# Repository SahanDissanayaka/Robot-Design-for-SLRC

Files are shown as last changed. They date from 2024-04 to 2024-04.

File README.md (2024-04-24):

# Robot Design for SLRC

## About SLRC
The Sri Lankan Robotics Challenge (SLRC) is a competition organized by the Department of Electronic and Telecommunication Engineering, University of Moratuwa. It has two categories: the School Category and the University Category.

## The Team
We are a team of five undergraduates from the Department of Electronic and Telecommunication Engineering, University of Moratuwa, known collectively as "We are Groot." Our team members are:

1. Sahan Dissanayaka
2. Senum Dodangoda
3. Sandaru Liyanaarachchi
4. Pasindu Kulasingham
5. Dilshan Nuwantha

Team

We proudly achieved a top 15 position in the university category and emerged as finalists in the competition.

## Our Task
Our project tasks are inspired by the concept of infinity stones in the Avengers Movie. For detailed information, please refer to the attached PDF document.

[Download Task PDF](https://ent.uom.lk/wp-content/uploads/2024/01/SLRC-2024-University-Category-v1.pdf)

## Our Robot
R2
R1

## Project Tasks
Consists of three planets
1. Planet A - Mountains in Vormir
2. Planet B - Ruins in Sakaar
3. Planet C - Thanos’s Home

- Line Following
- Wall Color Detection
- Color Junction Detection
- 3D Object Detection
- Metal Box Detection and Grabbing
- Wall Following
- Obstacle Height Detection

## Methodology

Each task was executed using advanced sensors and control algorithms:

### Line Following
Utilized an IR array in conjunction with a PID controller for accurate line tracking.

### Wall Color Detection
Employed a ToF sensor for wall detection and a rear-mounted color sensor for precise color identification.

### Color Junction Detection
Utilized strategically placed under-mounted color sensors to detect color junctions effectively.

### 3D Object Detection
Utilized advanced ToF sensor technology to accurately detect the shapes of objects.

### Metal Box Detection and Grabbing
Implemented conductivity testing to identify metal boxes and utilized a robotic arm for efficient grabbing.

### Wall Following
Employed a combination of front and side-mounted ultrasonic sensors for effective wall following.

### Height Detection
Utilized a combination of ToF and ultrasonic sensors to accurately measure object heights.

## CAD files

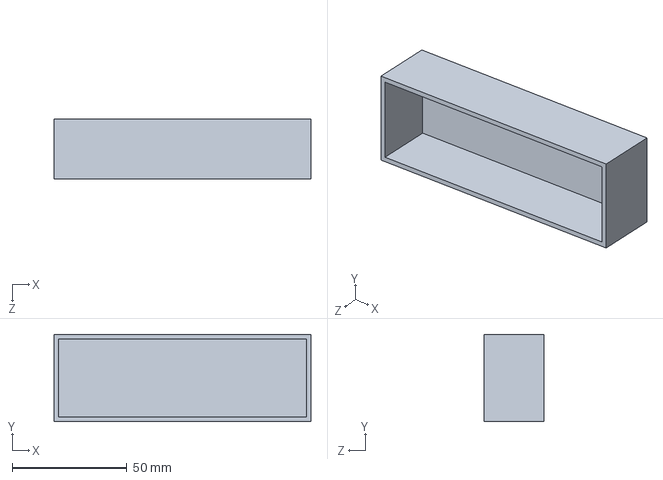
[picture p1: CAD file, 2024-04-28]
SolidWorks/Battery Holder/Assem1.SLDASM
112.0 x 38.0 x 26.0 mm

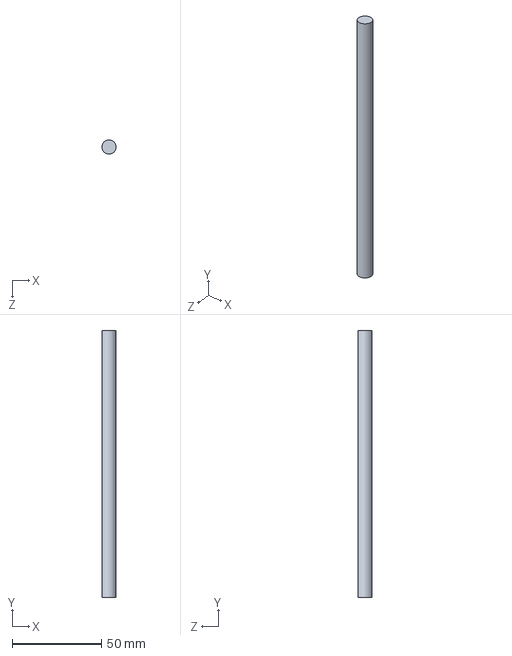
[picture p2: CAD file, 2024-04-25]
Robo Arm/rod right.SLDPRT
7.96 x 150.0 x 8.00 mm

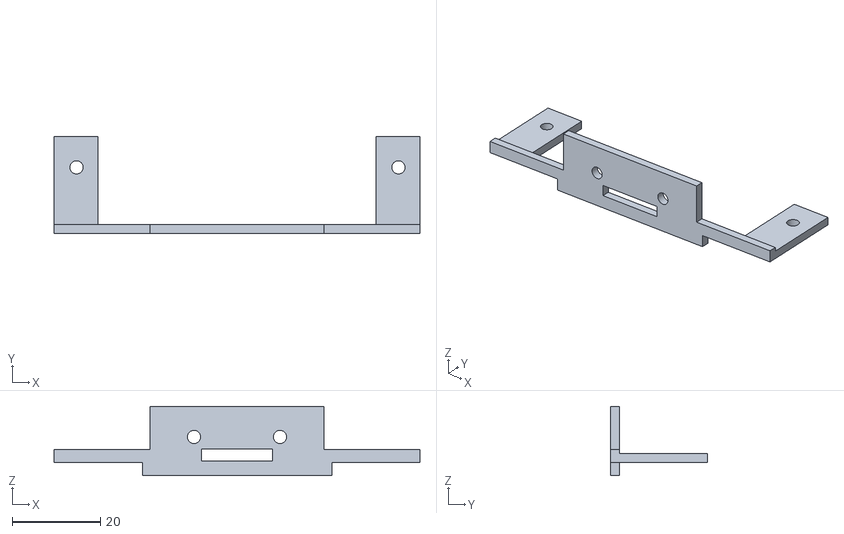
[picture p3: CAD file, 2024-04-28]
SolidWorks/Enclosure/3D Print/ToF sensor Front Holder.STL
83.0 x 22.0 x 15.8

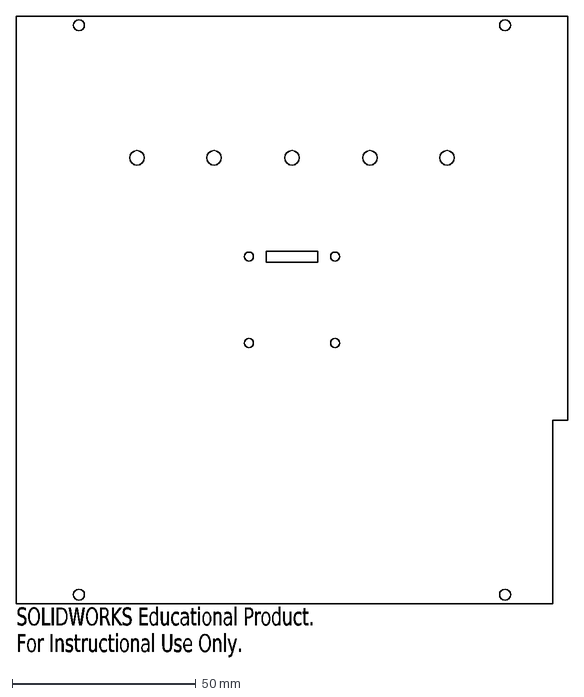
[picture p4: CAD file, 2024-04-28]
SolidWorks/Enclosure/Laser Cut/Top Part.DXF
SOLIDWORKS Educational Product.
For Instructional Use Only.

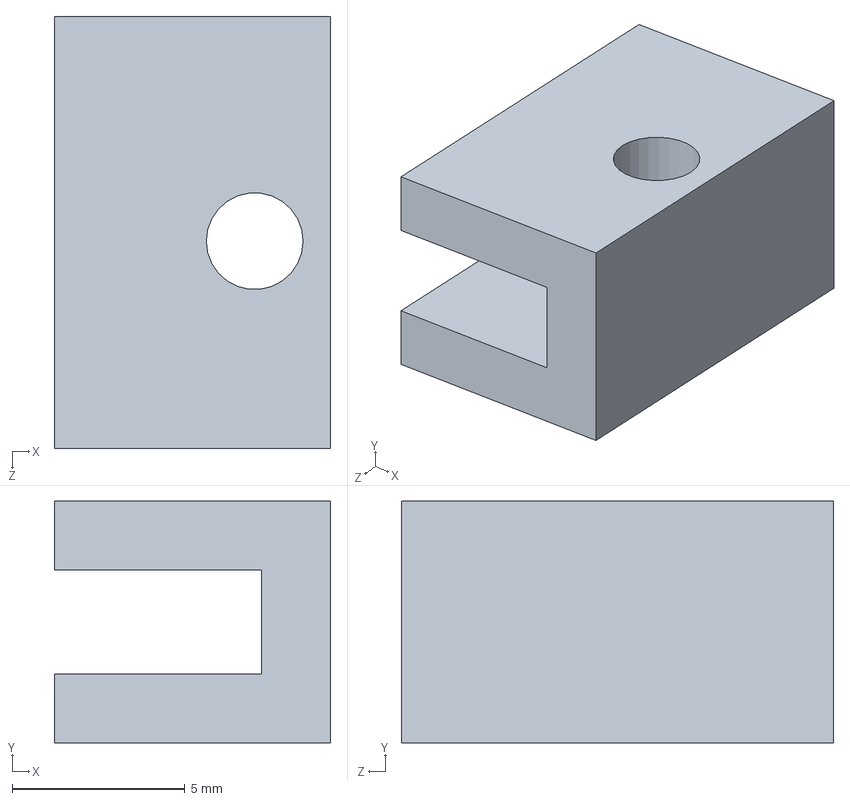
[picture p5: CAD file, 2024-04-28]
SolidWorks/Enclosure/Servo Holder.SLDPRT
8.00 x 7.00 x 12.5 mm

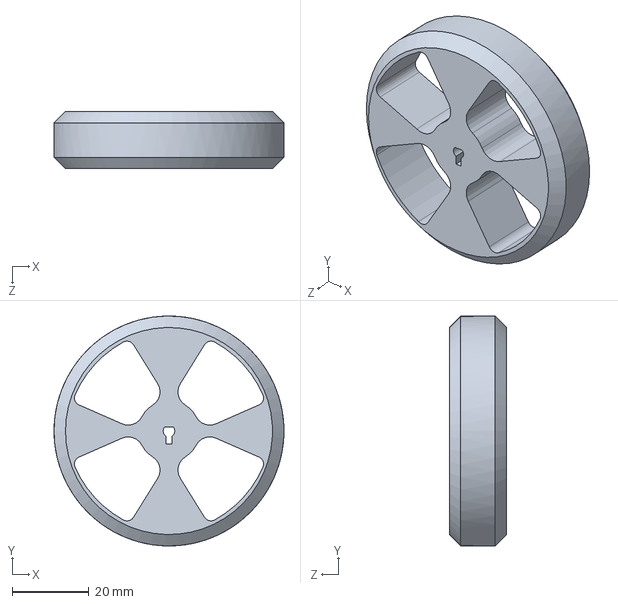
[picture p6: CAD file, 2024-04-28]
SolidWorks/Wheel/6cm.SLDPRT
60.0 x 60.0 x 15.0 mm

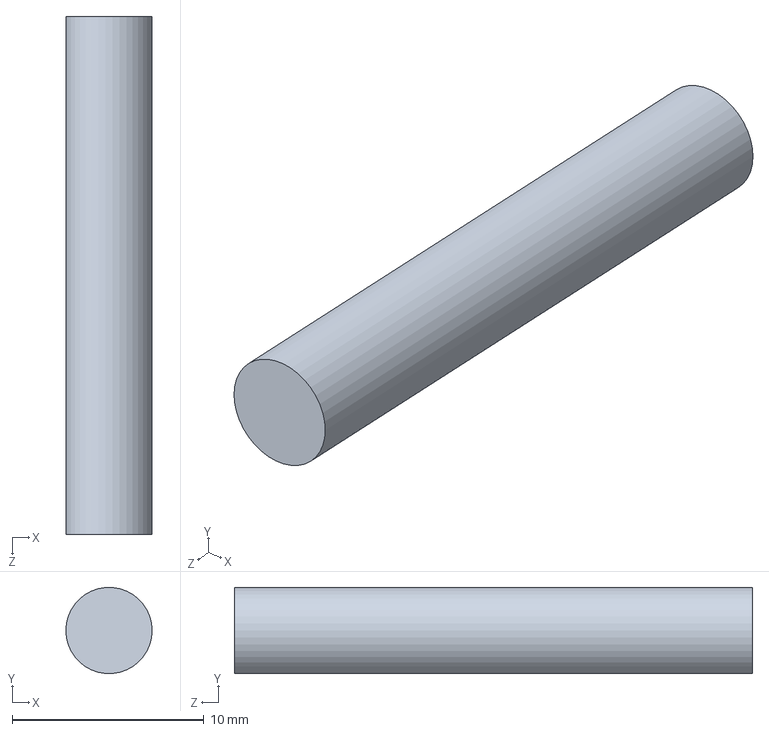
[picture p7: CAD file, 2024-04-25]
Robo Arm/pin upper.SLDPRT
4.50 x 4.48 x 27.0 mm

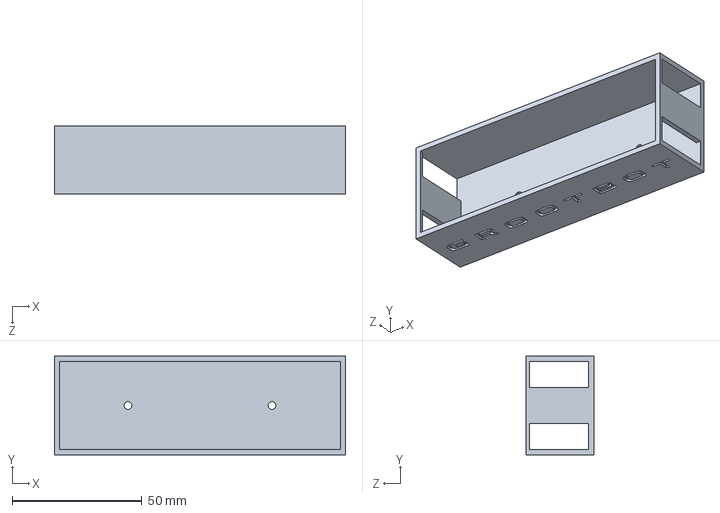
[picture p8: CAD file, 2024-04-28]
SolidWorks/Battery Holder/Battery holder.SLDPRT
112.0 x 38.0 x 26.0 mm

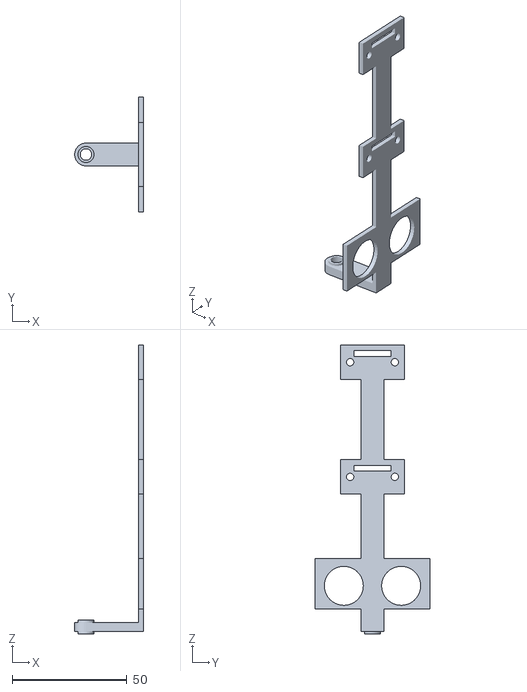
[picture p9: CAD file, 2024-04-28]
SolidWorks/Enclosure/3D Print/sensor tower.STL
29.9 x 50.0 x 126.0

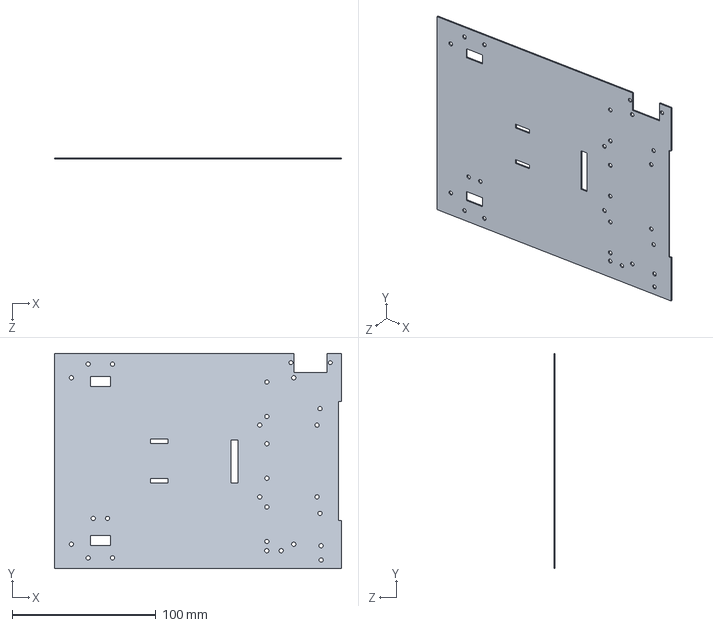
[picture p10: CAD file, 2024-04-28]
SolidWorks/Enclosure/Chassis1.SLDPRT
200.0 x 150.0 x 1.00 mm

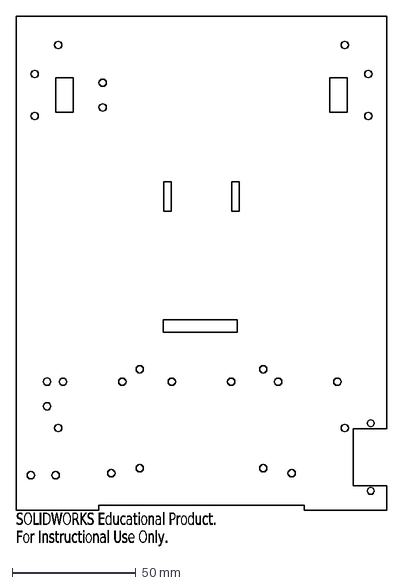
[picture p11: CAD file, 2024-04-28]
SolidWorks/Enclosure/Laser Cut/Chassis1.DXF
SOLIDWORKS Educational Product.
For Instructional Use Only.

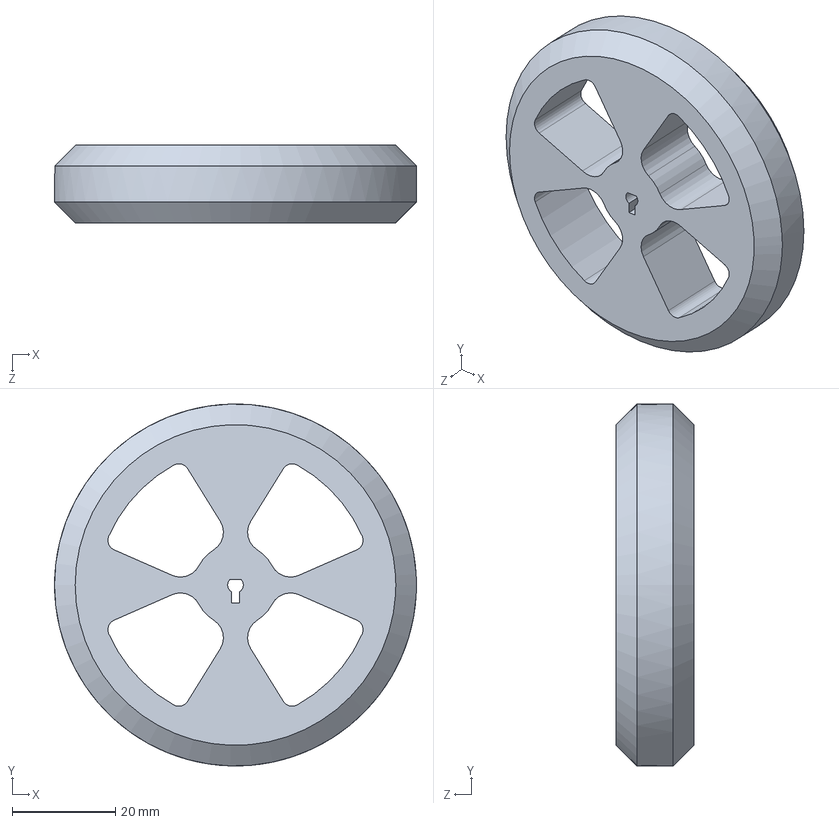
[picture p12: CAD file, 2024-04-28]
SolidWorks/Wheel/7cm.SLDPRT
70.0 x 70.0 x 15.0 mm

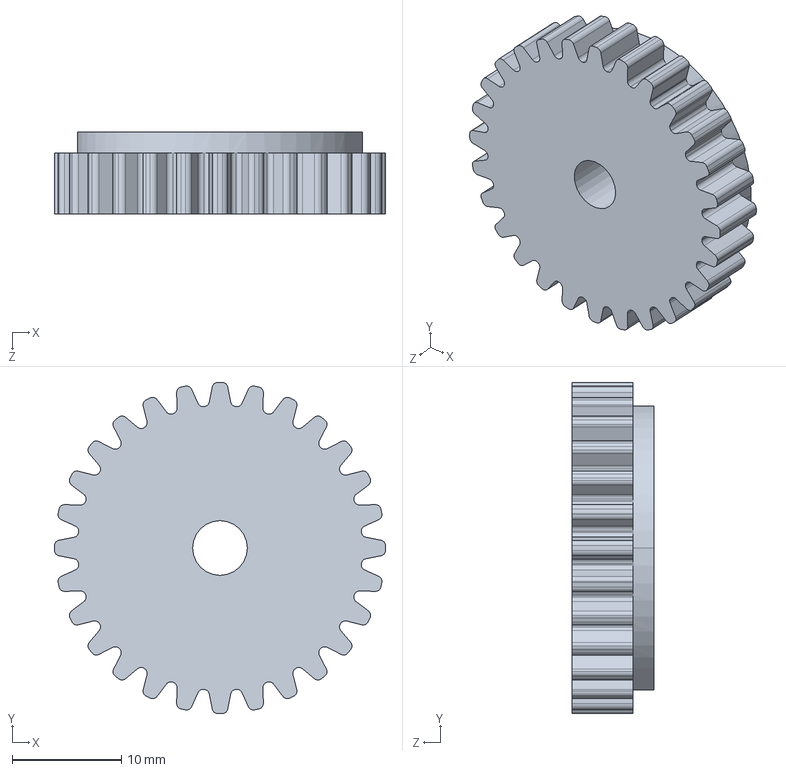
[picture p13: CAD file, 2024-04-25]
Robo Arm/Pinion Gear, Large Version.SLDPRT
30.2 x 30.2 x 7.51 mm

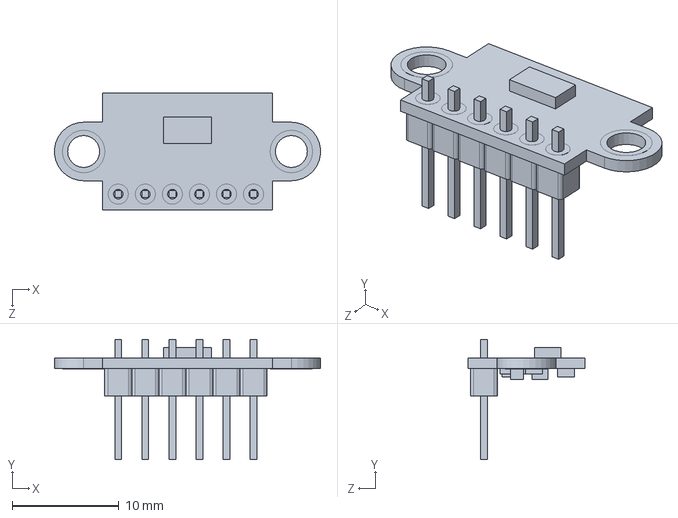
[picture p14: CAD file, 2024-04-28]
SolidWorks/Enclosure/ToF_vl53l0x.SLDPRT
25.0 x 11.3 x 11.0 mm

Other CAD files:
Robo Arm/overall arm.SLDASM
Robo Arm/Pusher, 75mm Long left.SLDPRT
SolidWorks/Enclosure/M3 Spacer MF 30mm.SLDPRT
Robo Arm/motor clip.SLDPRT
Robo Arm/Pusher, 75mm Long right.SLDPRT
Robo Arm/base.SLDPRT
Robo Arm/lower base.SLDPRT
Robo Arm/upper base.SLDPRT
SolidWorks/Battery Holder/Battery holder.STL
SolidWorks/Enclosure/3D Print/Servo Holder.STL
SolidWorks/Enclosure/3D Print/ToF Holder.STL
SolidWorks/Enclosure/3D Print/Ultrasonic Holder.STL
SolidWorks/Enclosure/Chassis.SLDPRT
SolidWorks/Enclosure/HCSR04 Ultrasonic Sensor.SLDPRT
SolidWorks/Enclosure/IR Array.SLDPRT
SolidWorks/Enclosure/IR holder.SLDPRT
SolidWorks/Enclosure/IR holder.STL
SolidWorks/Enclosure/TCS3200 color sensor.SLDPRT
SolidWorks/Enclosure/ToF Holder.SLDPRT
SolidWorks/Enclosure/ToF snsor Front Holder.SLDPRT
SolidWorks/Enclosure/Top Part.SLDPRT
SolidWorks/Enclosure/Ultrasonic Holder.SLDPRT
SolidWorks/Wheel/6cm.STL
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

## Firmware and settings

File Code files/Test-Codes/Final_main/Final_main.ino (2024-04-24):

#include <NewPing.h>
#include <MPU6050_light.h>
#include <Wire.h>
#include <Adafruit_GFX.h>
#include <Adafruit_SSD1306.h>
#include "Adafruit_TCS34725.h"
#include <VL53L0X.h>
#include <Servo.h>

// display
#define screen_width 128
#define screen_height 64
#define oled_reset -1
#define screen_address 0x3C

//LEDs
#define Green1 46
#define Blue1 52
#define Green2 44
#define Blue2 50
#define Red 48

// servo
#define SERVO_PIN 4


// IR array
#define IR1 45
#define IR2 43
#define IR3 41
#define IR4 39
#define IR5 37
#define IR6 35
#define IR7 33
#define IR8 31
#define IRL 12
#define IRR 13

// LEDs
// #define Green_LED 46
// #define Blue_LED 52
bool object_detected = false;

int task_count = 1;

// Arm
#define ArmMotorA 30
#define ArmMotorB 28
#define ArmMotorPWM 8


// Motors
#define LMotorA 51
#define LMotorB 53
#define LMotorPWM 2

#define RMotorA 49
#define RMotorB 47
#define RMotorPWM 3

int offset = 4;

// Metal
#define metal A0

#define MAX_SPEED 240

// Color Front
#define FS0 42
#define FS1 40
#define FS2 38
#define FS3 36
#define FsensorOut 32

int FredMin = 54;
int FredMax = 379;
int FgreenMin = 57;
int FgreenMax = 407;
int FblueMin = 50;
int FblueMax = 373;

// Variables for Color Pulse Width Measurements
int FredPW = 0;
int FgreenPW = 0;
int FbluePW = 0;

int FredValue;
int FgreenValue;
int FblueValue;

int distance;
String wall_colour;
bool got_colour = false;

// color back
#define S0 29
#define S1 27
#define S2 25
#define S3 23
#define sensorOut 34

int redMin = 86;
int redMax = 507;
int greenMin = 88;
int greenMax = 538;
int blueMin = 79;
int blueMax = 494;

// Variables for Color Pulse Width Measurements
int redPW = 0;
int greenPW = 0;
int bluePW = 0;

int redValue;
int greenValue;
int blueValue;

//detecting colour
String detected_color;

uint16_t red, green, blue, clear;

bool path_founded = false;

// Objects
Adafruit_SSD1306 display(screen_width, screen_height, &Wire, oled_reset);
Adafruit_TCS34725 tcs = Adafruit_TCS34725(TCS34725_INTEGRATIONTIME_50MS, TCS34725_GAIN_4X);
Servo servoMotor;
VL53L0X sensor1;
VL53L0X sensor2;
VL53L0X sensor3;
VL53L0X sensor4;
VL53L0X sensor5;

int IR_left = 0;
int IR_right = 0;
int IR_val[8] = { 0, 0, 0, 0, 0, 0, 0, 0 };
int IR_weights[8] = { -20, -15, -10, -5, 5, 10, 15, 20 };
float P = 0, I = 0, D = 0;
float error;
float previousError = 0;
float Kp = 1.5, Ki = 0, Kd = 0;
int speedAdjust = 0;
int box_grapped = 0;
int box_palce = 0;

void read_IR();
void PID_control();
void normal_line_follow();
void line_follow();
void mdrive(int ml, int mr);
void F_color_ditection();
void tast2_line_follow();
void path_detection();
int tof_distance_2();
void object_detection();
void box();
void find_box();
void check_metal();
void place_box();
void final();
void driveArmMotor(int speed, int Del);
void servo_dis(int x1, int x2);
void servo_in(int x1, int x2);
void displayDistance();
void turn_left();
void turn_right();
bool noLineDetected();
void adjustDirection();
void adjustSpeed();
void display_line(String text, int column, int row, int text_size);
bool t_junction_1();
bool t_junction_2();
bool t_junction_3();
bool t_junction_4();

String F_get_color();
String color();

// Angle turning
float P_angle, I_angle, D_angle;
float error_angle;
float previousError_angle = 0;
float Kp_angle = 6.5;
float Kd_angle = 0;
float Ki_angle = 0;
int speedAdjust_angle = 0;

MPU6050 mpu(Wire);
unsigned long timer = 0;

void zreadings();
void PID_control_angle(float target_angle, float current_initial_angle);
void turn_angle(float target_angle);

//Object detection
int count = 0;
int distance_array[100];
int array_size = 100;
float varience = 0;
float mean;
int total;

#define USL1_Trig 24
#define USL1_Echo 14

#define USF1_Trig 26
#define USF1_Echo 19

#define UST_Trig 11
#define UST_Echo 10

#define USTD_Trig 22
#define USTD_Echo 18

#define max_distance 100
#define safety_distance 8

NewPing SonarL1(USL1_Trig, USL1_Echo, max_distance);
NewPing SonarF1(USF1_Trig, USF1_Echo, max_distance);
NewPing SonarT(UST_Trig, UST_Echo, max_distance);
NewPing SonarTD(USTD_Trig, USTD_Echo, max_distance);

int Us_val[4] = { 0, 0, 0, 0 };
float Pw, Iw, Dw;
int errorw = 0;
float previousErrorw = 0;
float Kpw = 5;
float Kdw = 0;
float Kiw = 0;

int speedAdjustw = 0;

float angle_before_turn;
float angle_after_turn;

bool check_wall();
int angle = 20;
int pos = 10;
bool tower_in_left = false;
bool tower_in_middle = false;
int middle_dist;
int up_dist;
int height;
int max_height = 0;
bool max_height_found = false;
bool check_near_tower();
bool is_wall_present();
bool check_away_tower();
void check_height_away();
bool check_for_walls();
bool wall_follow_finished = false;

bool wall_at_left = false;
bool wall_at_right = false;
bool wall_following = false;


void TCA9548A(uint8_t bus) {
  Wire.beginTransmission(0x70);  // TCA9548A address is 0x70
  Wire.write(1 << bus);          // send byte to select bus
  Wire.endTransmission();
}

void setup() {
  Serial.begin(9600);

  if (!display.begin(SSD1306_SWITCHCAPVCC, screen_address)) {
    Serial.println(F("SSD1306 allocation failed"));
    while (true) {}
  }
  Serial.println("display is ok");

  display.display();
  delay(2000);

  display.clearDisplay();
  display_line("We Groot", 0, 0, 2);

  servoMotor.attach(SERVO_PIN);
  pinMode(ArmMotorA, OUTPUT);
  pinMode(ArmMotorB, OUTPUT);
  pinMode(ArmMotorPWM, OUTPUT);
  pinMode(LMotorA, OUTPUT);
  pinMode(LMotorB, OUTPUT);
  pinMode(LMotorPWM, OUTPUT);
  pinMode(RMotorA, OUTPUT);
  pinMode(RMotorB, OUTPUT);
  pinMode(RMotorPWM, OUTPUT);
  // pinMode(Green_LED, OUTPUT);
  // pinMode(Blue_LED, OUTPUT);

  pinMode(Green1, OUTPUT);
  pinMode(Blue1, OUTPUT);
  pinMode(Green2, OUTPUT);
  pinMode(Blue2, OUTPUT);
  pinMode(Red, OUTPUT);

  Serial.println("Tof testing");

  Wire.begin();


  TCA9548A(0);

  if (tcs.begin()) {
    Serial.println("Found sensor");
  } 
  else {
    Serial.println("No TCS34725 found ... check your connections");
    while (1);
  }
  Serial.println("1 ok");

  // TOF sensors
  TCA9548A(1);

  sensor1.setTimeout(500);
  if (!sensor1.init()) {
    Serial.println("Failed to detect and initialize sensor1!");
    while (1) {}
  }
  sensor1.startContinuous();
  Serial.println("1 ok");

  TCA9548A(2);

  sensor2.setTimeout(500);
  if (!sensor2.init()) {
    Serial.println("Failed to detect and initialize sensor2!");
    while (1) {}
  }
  sensor2.startContinuous();
  Serial.println("2 ok");

  TCA9548A(3);

  sensor3.setTimeout(500);
  if (!sensor3.init()) {
    Serial.println("Failed to detect and initialize sensor3!");
    while (1) {}
  }
  sensor3.startContinuous();
  Serial.println("3 ok");

  TCA9548A(4);

  sensor4.setTimeout(500);
  if (!sensor4.init()) {
    Serial.println("Failed to detect and initialize sensor4!");
    while (1) {}
  }
  sensor4.startContinuous();
  Serial.println("4 ok");

  TCA9548A(5);

  sensor5.setTimeout(500);
  if (!sensor5.init()) {
    Serial.println("Failed to detect and initialize sensor5!");
    while (1) {}
  }
  sensor5.startContinuous();
  Serial.println("5 ok");

  // Arm Servo
  servo_in(0, 60);

  // Gyro
  mpu.begin();
  //Serial.println("Calculating gyro offset, do not move MPU6050");
  mpu.calcGyroOffsets();

  // color back
  pinMode(S0, OUTPUT);
  pinMode(S1, OUTPUT);
  pinMode(S2, OUTPUT);
  pinMode(S3, OUTPUT);

  // Set Sensor output as input
  pinMode(sensorOut, INPUT);

  // Set Pulse Width scaling to 20%
  digitalWrite(S0, HIGH);
  digitalWrite(S1, LOW);

  // color front

  pinMode(FS0, OUTPUT);
  pinMode(FS1, OUTPUT);
  pinMode(FS2, OUTPUT);
  pinMode(FS3, OUTPUT);

  // Set Sensor output as input
  pinMode(FsensorOut, INPUT);

  // Set Pulse Width scaling to 20%
  digitalWrite(FS0, HIGH);
  digitalWrite(FS1, LOW);

  // if (tcs.begin()) {
  // } else {
  //   Serial.println("No TCS34725 found ... check your connections");
  //   while (1); // halt!
  // }
}

void loop() {
  // Serial.println(R_get_color());
  // object_detection();
  // normal_line_follow();
  // F_color_ditection();
  if(task_count == 1){
    display.clearDisplay();
    display_line("task1",0,20,2);
    F_color_ditection();

  }else if(task_count == 2){
    display.clearDisplay();
    display_line("task2",0,20,2);
    tast2_line_follow();

  }else if(task_count == 3){
    display.clearDisplay();
    display_line("task3",0,20,2);
    path_detection();
  }
  else 
  if(task_count == 4){
    display.clearDisplay();
    display_line("task4",0,20,2);
    object_detection();
  }
  else if(task_count == 5){
    display.clearDisplay();
    display_line("task5",0,20,2);
    tast4_line_follow();
  }
  else if(task_count == 6){
    display.clearDisplay();
    display_line("task6",0,20,2);
    if (wall_colour == "Green"){
      task5_Green();
    }
    else{
      task5_Blue();
    }
  }
  else if(task_count == 7){
    display.clearDisplay();
    display_line("task7",0,20,2);
    box();
  }
  else if(task_count == 8){
    display.clearDisplay();
    display_line("task8",0,20,2);
    place_box();
  }
  
  else if(task_count == 9){
    final();
    display.clearDisplay();
    display_line("task9",0,20,2);
  }
  else if(task_count == 10){
    display.clearDisplay();
    display_line("task10",0,20,2);
    planetb();
  }
  //  if(task_count == 1){
  //     box();
  //     display.clearDisplay();
  //     display_line("task6",0,20,2);
  //   }
  //   else if(task_count == 2){
  //     place_box();
  //     display.clearDisplay();
  //     display_line("task7",0,20,2);
  //   }

  //   else if(task_count == 3){
  //     final();
  //     display.clearDisplay();
  //     display_line("task8",0,20,2);
  //   }
  // mdrive(90,90);
}

// TASK 1 ------Wall Color
void F_color_ditection() {
  if (!got_colour) {
    TCA9548A(2);
    distance = sensor2.readRangeContinuousMillimeters() / 10;
    display.clearDisplay();
    display_line(String(distance), 0, 0, 2);

    if (distance <= 8) {
      mdrive(0, 0);
      delay(500);
      turn_angle(180);
      TCA9548A(5);
      int d = sensor5.readRangeContinuousMillimeters() / 10;
      while (d >= 4) {
        mdrive(-100, -75);
        delay(10);
        TCA9548A(5);
        d = sensor5.readRangeContinuousMillimeters() / 10;
      }
      mdrive(0, 0);
      delay(100);
      wall_colour = F_get_color();
      display.clearDisplay();
      display_line(wall_colour, 0, 0, 2);
      delay(1000);
      got_colour = true;

    } else {
      read_IR();
      PID_control();
      int ml = 90;
      int mr = 90;

      mdrive(ml + speedAdjust, mr - speedAdjust);
    }
  } 
  else {
    read_IR();
    if (IR_left == 0 && IR_val[7] == 1 && IR_val[6] == 1 && IR_val[2] == 1 && IR_val[3] == 1 && IR_val[4] == 1 && IR_val[5] == 1 && IR_right == 1) {
      mdrive(90, 90);
      delay(1700);
      while (!noLineDetected()) {
        read_IR();
        mdrive(90, -90);
      }
      while (IR_val[3] == 0 && IR_val[4] == 0) {
        read_IR();  // Corrected function call
        mdrive(90, -90);
        delay(10);
      }
      mdrive(0, 0);
      delay(10);
      task_count++;
      read_IR();
      PID_control();
      int ml = 90;
      int mr = 90;

      mdrive(ml + speedAdjust, mr - speedAdjust);


    } else {
      PID_control();
      int ml = 90;
      int mr = 90;

      mdrive(ml + speedAdjust, mr - speedAdjust);
    }
  }
}

// TASK 2
void tast2_line_follow() {
  read_IR();
  display.clearDisplay();
  display_line("2 now", 0, 0, 2);
  if (IR_val[0] == 1 && IR_val[1] == 1 && IR_val[2] == 1 && IR_val[3] == 1 && IR_val[4] == 1 && IR_val[5] == 1 && IR_val[6] == 1 && IR_val[7] == 1) {
    mdrive(90, 90);
    delay(2000);
    while (!noLineDetected()) {
      read_IR();
      mdrive(-90, 90);
    }
    turn_left();
    task_count++;
    display.clearDisplay();
    display_line("2 hari", 0, 0, 2);
  }

  else if (IR_val[0] == 1 && IR_val[1] == 1 && IR_val[2] == 1 && IR_val[3] == 1 && IR_val[4] == 1 && IR_val[5] == 1) {
    mdrive(90, 90);
    delay(2000);
    while (!noLineDetected()) {
      read_IR();
      mdrive(-90, 90);
    }
    while (IR_val[6] == 0 || IR_val[5] == 0) {
      read_IR();  // Corrected function call
      mdrive(-90, 90);
    }
    task_count++;
    display.clearDisplay();
    display_line("2 hari", 0, 0, 2);
    PID_control();
    int ml = 90;
    int mr = 90;

    mdrive(ml + speedAdjust, mr - speedAdjust);
  }

  // no line detection
  else if (IR_val[0] == 0 && IR_val[1] == 0 && IR_val[2] == 0 && IR_val[3] == 0 && IR_val[4] == 0 && IR_val[5] == 0 && IR_val[6] == 0 && IR_val[7] == 0) {
    if (previousError < 0) {
      mdrive(90, 90);
      delay(1500);
      turn_left();

    } else {
      mdrive(90, 90);
      delay(1500);
      turn_right();
    }

  } else {
    PID_control();
    int ml = 90;
    int mr = 90;

    mdrive(ml + speedAdjust, mr - speedAdjust);
  }
}

//TASK 3 ------Path detection
void path_detection() {
  if (!path_founded) {
    detected_color = color();
    if (detected_color == "Red") {
      String check_color = color();
      if (check_color == "Red") {
        Serial.println("Red found!!!");
        mdrive(0, 0);
        delay(1000);
        String right_color = R_get_color();
        delay(1000);

        if (right_color == wall_colour) {
          turn_angle(-90);
          path_founded = true;
        } else {
          turn_angle(90);
          path_founded = true;
        }
        task_count++;
      } else {
        normal_line_follow();
        Serial.println("AAA");
      }
    } else {
      Serial.println("BBB");
      normal_line_follow();
    }
  } else {
    Serial.println("CCC");
    line_follow();
  }
}

//TASK 4 ------object detection
void tast4_line_follow() {
  read_IR();

  // harahata
  if (IR_left == 1 && IR_val[0] == 1 && IR_val[1] == 1 && IR_val[2] == 1 && IR_val[3] == 1 && IR_val[4] == 1 && IR_val[5] == 1 && IR_val[6] == 1 && IR_val[7] == 1 && IR_right == 1) {
    mdrive(90, 90);
    // digitalWrite(Red,LOW);
    // digitalWrite(Green1,HIGH);
    delay(1500);
    // digitalWrite(Green1,LOW);
    while (!noLineDetected()) {
      read_IR();
      mdrive(-90, 90);
    }
    turn_left();
    task_count++;
  }

  // t junction to left
  else if (IR_left == 1 && IR_val[0] == 1 && IR_val[1] == 1 && IR_val[2] == 1 && IR_val[3] == 1 && IR_val[4] == 1 && IR_val[5] == 1 && IR_right == 0) {
    mdrive(90, 90);
    // digitalWrite(Red,LOW);
    // digitalWrite(Blue1,HIGH);
    delay(1500);
    // digitalWrite(Blue1,LOW);
    while (!noLineDetected()) {
      read_IR();
      mdrive(-90, 90);
    }
    while (IR_val[5] == 0 || IR_val[6] == 0) {
      read_IR();  // Corrected function call
      mdrive(-90, 90);
      delay(10);
    }
    task_count++;
  }

  // no line detection
  else if (IR_left == 0 && IR_val[2] == 1 && IR_val[3] == 1 && IR_val[4] == 1 && IR_val[5] == 1 && IR_val[6] == 1 && IR_val[7] == 1 && IR_right == 1) {
    delay(50);
    read_IR();
    if (IR_left == 1 || IR_val[0] == 1) {
      mdrive(90, 90);
      // digitalWrite(Red,LOW);
      // digitalWrite(Blue1,HIGH);
      delay(1500);
      // digitalWrite(Blue1,LOW);
      while (!noLineDetected()) {
        read_IR();
        mdrive(-90, 90);
      }
      while (IR_val[5] == 0 || IR_val[6] == 0) {
        read_IR();  // Corrected function call
        mdrive(-90, 90);
        delay(10);
      }
      task_count++;
    } else {
      mdrive(90, 90);
      // digitalWrite(Red,LOW);
      // digitalWrite(Green2,HIGH);
      delay(1500);
      // digitalWrite(Green2,LOW);
      read_IR();
      if (IR_left == 0 && IR_val[0] == 0 && IR_val[1] == 0 && IR_val[2] == 0 && IR_val[3] == 0 && IR_val[4] == 0 && IR_val[5] == 0 && IR_val[6] == 0 && IR_val[7] == 0 && IR_right == 0) {
        // digitalWrite(Blue2,HIGH);
        while (IR_val[1] == 0 || IR_val[0] == 0) {
          read_IR();  // Corrected function call
          mdrive(90, -90);
          delay(10);
        }
      } else {
        // digitalWrite(Red,HIGH);
        PID_control();
        int ml = 90;
        int mr = 90;

        mdrive(ml + speedAdjust, mr - speedAdjust);
      }
    }
  } else {
    read_IR();
    PID_control();
    int ml = 90;
    int mr = 90;

    mdrive(ml + speedAdjust, mr - speedAdjust);
  }
}

void object_detection() {
  if (!object_detected) {
    line_follow();
    if (count < 150) {
      normal_line_follow();
      TCA9548A(1);
      int distance1 = sensor1.readRangeContinuousMillimeters();
      if (distance1 < 230) {
        if (count>=50){
          distance_array[count-50] = distance1;
        }
        display.clearDisplay();
        display_line(String(count), 0, 10, 2);
        display_line(String(distance1), 0, 30, 2);
        count++;
      }
      while (count>0 && count<150){
        normal_line_follow();
        TCA9548A(1);
        int distance1 = sensor1.readRangeContinuousMillimeters();
        if (distance1 < 230) {
          if (count>=50){
            distance_array[count-50] = distance1;
          }
          display.clearDisplay();
          display_line(String(count), 0, 10, 2);
          display_line(String(distance1), 0, 30, 2);
          count++;
        }
      }

    } 
    else {
      total = 0;
      for (int i = 0; i < array_size; i++) {
        total += distance_array[i];
      }
      mean = total / 100.0;
      display.clearDisplay();
      display_line(String(mean), 0, 20, 2);

      varience = 0;
      for (int i = 0; i < array_size; i++) {
        varience += pow(distance_array[i] - mean, 2);
      }
      varience = varience / 100;
      display_line(String(varience), 0, 40, 2);

      if (varience <= 20) {
        // cylinder
        digitalWrite(Green1, HIGH);
        object_detected = true;
      } else {
        // cuboid
        digitalWrite(Blue1, HIGH);
        object_detected = true;
      }
      
    }
  }
  else{
    tast4_line_follow();
  }
  
}


//TASK 5
void task5_Blue() {
  detected_color = color();
  if (detected_color == "Green") {
    String check_color = color();
    if (check_color == "Green") {
      mdrive(0, 0);
      delay(1000);
      String left_color = L_get_color();
      delay(1000);
      if (left_color == "Red") {
        turn_angle(-90);
      } else {
        turn_angle(90);
      }
      task_count++;

    } else {
      read_IR();
      PID_control();
      int ml = 90;
      int mr = 90;

      mdrive(ml+speedAdjust, mr-speedAdjust);
    }
  } else {
      read_IR();
      PID_control();
      int ml = 90;
      int mr = 90;

      mdrive(ml+speedAdjust, mr-speedAdjust);
  }
}

void task5_Green() {
  detected_color = color();
  if (detected_color == "Blue") {
    String check_color = color();
    if (check_color == "Blue") {
      mdrive(0, 0);
      delay(1000);
      String left_color = L_get_color();
      delay(1000);
      if (left_color == "Red") {
        turn_angle(-90);
      } else {
        turn_angle(90);
      }
      task_count++;

    } else {
      read_IR();
      PID_control();
      int ml = 80;
      int mr = 80;

      mdrive(ml+speedAdjust, mr-speedAdjust);
    }
  } else {
      read_IR();
      PID_control();
      int ml = 80;
      int mr = 80;

      mdrive(ml+speedAdjust, mr-speedAdjust);
  }
}

//TASK 6 ------Box
void box() {
  
  read_IR();

  while (!(t_junction_3())) {
    read_IR();
    PID_control();
    int ml = 90;
    int mr = 90;

    mdrive(ml + speedAdjust, mr - speedAdjust);
  }
  mdrive(90, 90);
  delay(1800);
  read_IR();
  while (!noLineDetected()) {
    read_IR();
    mdrive(-90, 90);
  }
  turn_left();

  find_box();
  if (box_grapped == 1) {
    if (box_palce == 1) {
      while (!t_junction_3()) {
        read_IR();
        PID_control();
        int ml = 90;
        int mr = 90;
        mdrive(ml + speedAdjust, mr - speedAdjust);
      }
      mdrive(90, 90);
      delay(1600);
      read_IR();
      while (!noLineDetected()) {
        read_IR();
        mdrive(90, -90);
      }
      turn_right();
      mdrive(0, 0);
    } else if (box_palce == 2) {
      while (!t_junction_3()) {
        read_IR();
        PID_control();
        int ml = 90;
        int mr = 90;
        mdrive(ml + speedAdjust, mr - speedAdjust);
      }
      read_IR();
      PID_control();
      int ml = 90;
      int mr = 90;

      mdrive(ml + speedAdjust, mr - speedAdjust);
    } else if (box_palce == 3) {
      while (!t_junction_3()) {
        read_IR();
        PID_control();
        int ml = 90;
        int mr = 90;
        mdrive(ml + speedAdjust, mr - speedAdjust);
      }
      mdrive(90, 90);
      delay(1600);
      read_IR();
      while (!noLineDetected()) {
        read_IR();
        mdrive(-90, 90);
      }
      turn_left();
    }
    mdrive(90, 90);
    delay(1000);
    read_IR();
    
    delay(100);
    while (!t_junction_4()) {
      read_IR();
      PID_control();
      int ml = 90;
      int mr = 90;

      mdrive(ml + speedAdjust, mr - speedAdjust);
    }
    mdrive(90, 90);
    delay(2700);
    // unsigned long t = millis();
    // while(t-millis() < 2000){
    //   read_IR();
    //   PID_control();
    //   int ml = 90;
    //   int mr = 90;

    //   mdrive(ml+speedAdjust, mr-speedAdjust);
    //}
   
    read_IR();
    task_count++;
    // while(!t_junction_4()){
    //   read_IR();
    //   PID_control();
    //   int ml = 90;
    //   int mr = 90;

    //   mdrive(ml+speedAdjust, mr-speedAdjust);
    // }
    // mdrive(90,90);
    // delay(2000);
    // digitalWrite(Red, LOW);
    // turn_angle(90);
    // digitalWrite(Green1, LOW);
    // task_count ++;
    line_follow();
  }
}
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

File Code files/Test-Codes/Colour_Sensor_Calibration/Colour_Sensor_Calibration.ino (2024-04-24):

#include <Wire.h>
#include <Adafruit_GFX.h>
#include <Adafruit_SSD1306.h>

#define screen_width 128
#define screen_height 64
#define oled_reset -1
#define screen_address 0x3C

// #define S0 42
// #define S1 40
// #define S2 38
// #define S3 36
// #define sensorOut 32

#define S0 29
#define S1 27
#define S2 25
#define S3 23
#define sensorOut 34

int redMin = 54;
int redMax = 379;
int greenMin = 57;
int greenMax = 407;
int blueMin = 50;
int blueMax = 373;

// int redMin = 229;
// int redMax = 660;
// int greenMin = 271;
// int greenMax = 724;
// int blueMin = 270;
// int blueMax = 555;

// Variables for Color Pulse Width Measurements
int redPW = 0;
int greenPW = 0;
int bluePW = 0;

int redValue;
int greenValue;
int blueValue;

Adafruit_SSD1306 display(screen_width, screen_height, &Wire, oled_reset);

void display_line(String text, int column, int row, int text_size) {

  display.setTextSize(text_size);
  display.setTextColor(SSD1306_WHITE);
  display.setCursor(column, row);
  display.println(text);

  display.display();
}

void setup() {
  // Set pins 4 to 7 as outputs
  pinMode(S0, OUTPUT);
  pinMode(S1, OUTPUT);
  pinMode(S2, OUTPUT);
  pinMode(S3, OUTPUT);

  // Set Sensor output as input
  pinMode(sensorOut, INPUT);

  // Set Pulse Width scaling to 20%
  digitalWrite(S0, HIGH);
  digitalWrite(S1, LOW);

  // Setup Serial Monitor
  Serial.begin(9600);

  // if (!display.begin(SSD1306_SWITCHCAPVCC, screen_address)) {
  //   Serial.println(F("SSD1306 allocation failed"));
  //   while (true) {}
  // }

  // display.display();
  // delay(2000);

  // display.clearDisplay();
  // display_line("We are Groot", 0, 0,2);

  // Wire.begin();
}

void loop() {
  // Read Red Pulse Width
  redPW = getRedPW();
  redValue = map(redPW, redMin, redMax, 255, 0);
  // Delay to stabilize sensor
  //delay(200);

  // Read Green Pulse Width
  greenPW = getGreenPW();
  greenValue = map(greenPW, greenMin, greenMax, 255, 0);
  // Delay to stabilize sensor
  //delay(200);

  // Read Blue Pulse Width
  bluePW = getBluePW();
  blueValue = map(bluePW, blueMin, blueMax, 255, 0);
  // Delay to stabilize sensor
  //delay(200);

  // Print output to Serial Monitor
  Serial.print("Red = ");
  Serial.print(redValue);
  Serial.print(" - Green = ");
  Serial.print(greenValue);
  Serial.print(" - Blue = ");
  Serial.println(blueValue);

  // Determine the dominant color
  if (redValue > 230 && blueValue > 230 && greenValue > 230) {
    Serial.println("Color is White");
    // display.clearDisplay();
    // display_line("White", 0, 0,2);
  }
  else if(redValue < 100 && blueValue < 100 && greenValue < 100){
    Serial.println("Color is Black");
    // display.clearDisplay();
    // display_line("Black", 0, 0,2);
  }
  else {
    if (redValue > greenValue && redValue > blueValue) {
      Serial.println("Color is Red");
      // display.clearDisplay();
      // display_line("White", 0, 0,2);
    } else if (greenValue > redValue && greenValue > blueValue) {
      Serial.println("Color is Green");
      // display.clearDisplay();
      // display_line("Green", 0, 0,2);
    } else if (blueValue > greenValue && blueValue > redValue) {
      Serial.println("Color is Blue");
      // display.clearDisplay();
      // display_line("Blue", 0, 0,2);
    }
  }
}

// Function to read Red Pulse Widths
int getRedPW() {
  // Set sensor to read Red only
  digitalWrite(S2, LOW);
  digitalWrite(S3, LOW);

  // Read the output Pulse Width
  int PW = pulseIn(sensorOut, LOW);

  // Return the value
  return PW;
}

// Function to read Green Pulse Widths
int getGreenPW() {
  // Set sensor to read Green only
  digitalWrite(S2, HIGH);
  digitalWrite(S3, HIGH);

  // Read the output Pulse Width
  int PW = pulseIn(sensorOut, LOW);

  // Return the value
  return PW;
}

// Function to read Blue Pulse Widths
int getBluePW() {
  // Set sensor to read Blue only
  digitalWrite(S2, LOW);
  digitalWrite(S3, HIGH);

  // Read the output Pulse Width
  int PW = pulseIn(sensorOut, LOW);

  // Return the value
  return PW;
}

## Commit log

2024-04-24 Create a folder to add pcb design files
2024-05-02 Create PCB Design
